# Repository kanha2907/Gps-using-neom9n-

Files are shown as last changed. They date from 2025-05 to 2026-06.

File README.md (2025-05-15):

# Gps-using-neom9n-
      Compact GPS breakout board based on the u-blox NEO-M9N module. Includes support circuitry for battery-backed operation, LEDs, and passives—designed for low-power embedded GPS applications.

# GPS_M Module – Compact GPS Breakout Board

> Compact GPS breakout board based on the **u-blox NEO-M9N** module. Includes support circuitry for battery-backed operation, LEDs, and passives—designed for low-power embedded GPS applications.

---

## 📦 Files Included

- `GPS_m_gerber/`: Full set of Gerber files for PCB manufacturing.
- `neom9n.csv`: Bill of Materials (BOM) with part references, values, and footprints.

## 🧩 Overview

- **GPS Chip:** u-blox NEO-M9N
- **Power Source:** Designed for coin cell MS621T-FL11E
- **Form Factor:** Compact dual-layer board
- **Ideal For:** GPS logging, time synchronization, compact embedded systems

## 🔩 Components Overview

| Reference | Value | Footprint | Quantity |
|---|---|---|---|
| B1 | 6.8MM Coin Cell | MS621T-FL11E | 1 |
| C1 | 47pF Capacitor | GRM1885C1H470JA01D | 1 |
| C3–C6 | 1uF Capacitors | GRM21BR61C105KA01L | 4 |
| CR1 | 1N4148WX-TP Diode | CR_SOD323_MCC | 1 |
| D1, D4 | LEDs | WL-SMCW_0603 | 2 |
| ... | *(See full BOM file)* | | |

> 💡 For the full list of components, refer to `neom9n.csv`.

## 🛠️ How to Use

1. **Order the PCB** using the Gerber files in the `GPS_m_gerber/` folder.
2. **Order parts** based on the BOM file `neom9n.csv`.
3. **Assemble the board** using standard SMD soldering practices.

## 📎 License

This hardware design is released under the [CERN-OHL-W v2](https://ohwr.org/project/cernohl/wikis/home) open hardware license.

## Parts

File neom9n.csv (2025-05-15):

Reference | Value | Datasheet | Footprint | Qty | DNP
B1 | 6.8MM_COIN_CELL |  | MS621T-FL11E:MS621FE-FL11E | 1
C1 | GRM1885C1H470JA01D |  | GRM1885C1H470JA01D:G-188_MUR-L | 1
C3,C4,C5,C6 | GRM21BR61C105KA01L |  | GRM21BR61C105KA01L:CAPC2012X135N | 4
CR1 | 1N4148WX-TP | 1N4148WX-TP | 1N4148WX_TP:CR_SOD323_MCC | 1
D1,D4 | WL-SMCW_0603 |  | 150060BS75000:WL-SMCW_0603 | 2
D3 | PRTR5V0U2F |  | PRTR5V0U2F:FNL6_SOT886_NEX-L | 1
FB1 | BLM21AG102SN1D |  | BLM21AG102SN1D:IND_BLM21_MUR | 1
J1 | SM08B-GHS-TB_LF__SN_ |  | SM08B-GHS-TB_LF__SN_:JST_SM08B-GHS-TB_LF__SN_ | 1
J2,J4,J5,J6 | SM04B-GHS-TB_LF__SN_- |  | SM04B-GHS-TB_LF__SN_-:JST_SM04B-GHS-TB_LF__SN_- | 4
J3 | USB4105-GF-A-060 |  | USB4105-GF-A-060:GCT_USB4105-GF-A-060 | 1
J7 | U.FL-R-SMT-1_10_ |  | U_FL_R_SMT_1_10_:HRS_U.FL-R-SMT-1_10_ | 1
PPS0,PWR\0,SPI0,W1 | 5102TR |  | 5102TR:KEYSTONE_5102TR | 4
R1,R5,R11 | CFR-25JB-52-1K |  | CFR-25JB-52-1K:YAG_CFR25_YAG | 3
R2,R3,R4,R6 | RMCF1206JT33R0 |  | RC0603N_YAG_33:RC0603N_YAG-M | 4
R7 | RC0402FR-072K2L: |  | RC0402FR-072K2L:RC0402N_YAG | 1
R8 | RC0402FR-072K2L |  | RC0402FR-072K2L:RC0402N_YAG-M | 1
R9,R10 | CF12JT27R0 | CF12JT27R0 | CF12JT27R0:RES_CF12_STP | 2
R12,R13 | CRCW06035K10FKEAC |  | CRCW06035K10FKEAC:RESC1608X55N | 2
R14 | SQP10AJB_10R |  | SQP10AJB_10R:YAG_SQP10_YAG | 1
R15 | RC0402FR-07100KL | RC0402FR-07100KL | RC0402N_YAG | 1
R16 | CFR-25JB-52-10K |  | CFR-25JB-52-10K:YAG_CFR25_YAG | 1
U1 | U-BLOX_NEO-M9N |  | RF_GPS:ublox_NEO | 1
U2 | AMS1117-3.3 | http://www.advanced-monolithic.com/pdf/ds1117.pdf | Package_TO_SOT_SMD:SOT-223-3_TabPin2 | 1

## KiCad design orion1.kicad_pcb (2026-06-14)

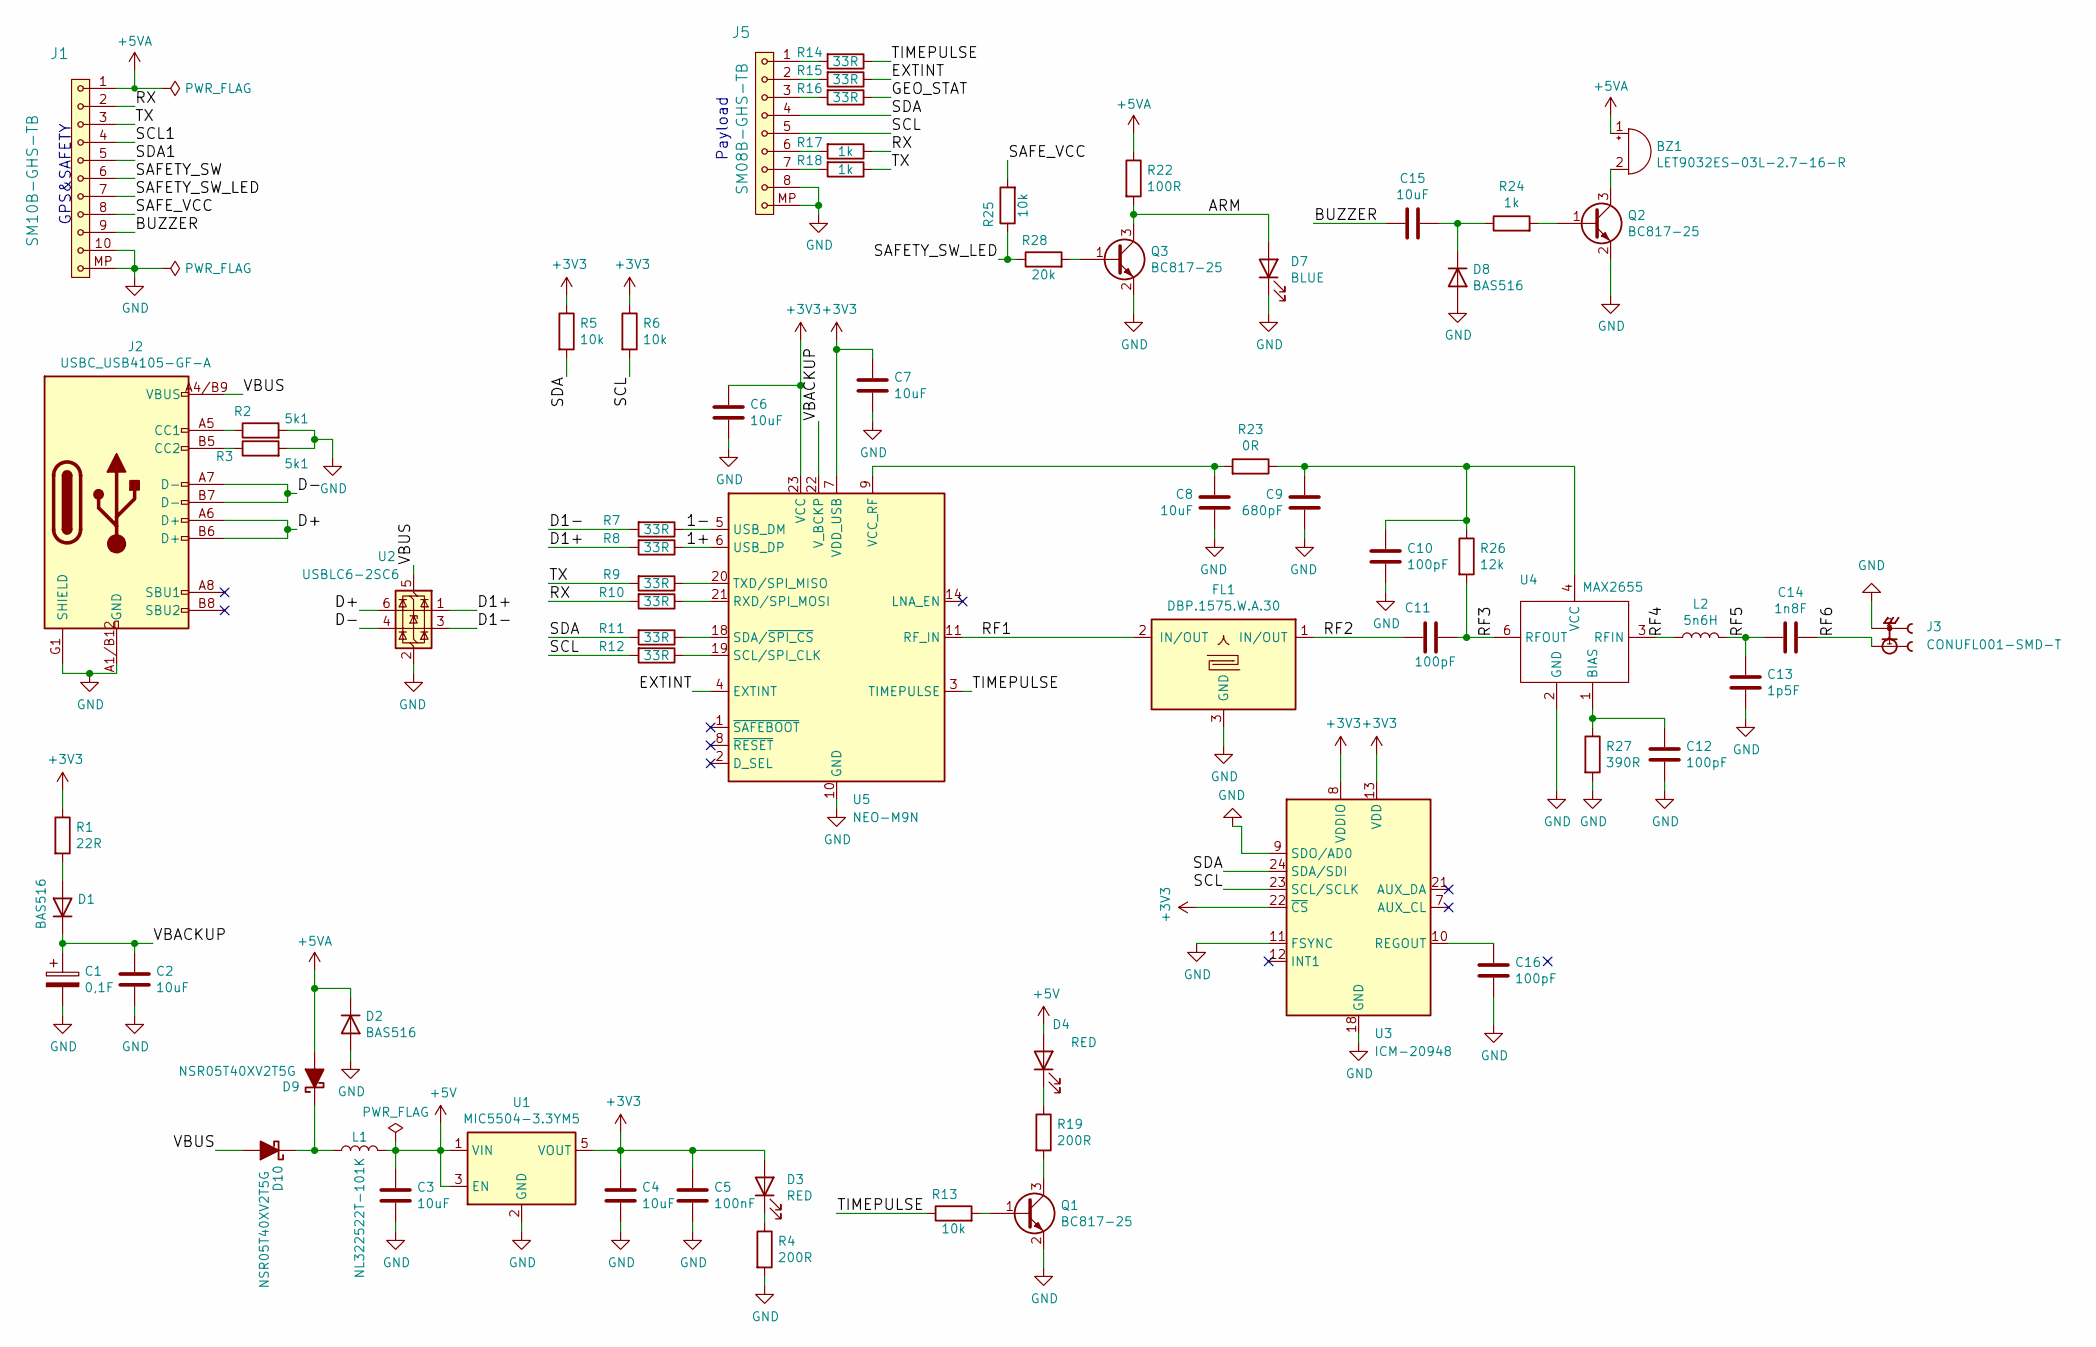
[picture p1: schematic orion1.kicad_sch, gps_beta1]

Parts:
BZ1: LET9032ES-03L-2.7-16-R; MagneticBuzzer_LET9032ES-03L-2.7-16-R
C1: 0,1F; CP_Elec_10x10.5
C2, C3, C4, C6, C7, C8, C15: 10uF; C_0805_2012Metric
C5: 100nF; C_0805_2012Metric
C9: 680pF; C_0805_2012Metric
C10, C11, C12, C16: 100pF; C_0805_2012Metric
C13: 1p5F; C_0805_2012Metric
C14: 1n8F; C_0805_2012Metric
D1, D2, D8: BAS516; D_SOD-523
D3, D4: RED; LED_1206_mill
D7: BLUE; LED_1206_mill
D9, D10: NSR05T40XV2T5G; D_SOD-523
FL1: DBP.1575.W.A.30; SAW DBP.1575.W.A.30
J1: SM10B-GHS-TB; JST_GH_SM10B-GHS-TB_1x10-1MP_P1.25mm_Horizontal
J2: USBC_USB4105-GF-A; USBC GCT_USB4105-GF-A
J3: CONUFL001-SMD-T; LINX_CONUFL001-SMD-T
J5: SM08B-GHS-TB; JST_GH_SM08B-GHS-TB_1x08-1MP_P1.25mm_Horizontal
L1: NL322522T-101K; L_1210_3225Metric
L2: 5n6H; L_0805_2012Metric
Q1, Q2, Q3: BC817-25; SOT-23
R1: 22R; R_0805_2012Metric
R2, R3: 5k1; R_0805_2012Metric
R4, R19: 200R; R_0805_2012Metric
R5, R6, R13, R25: 10k; R_0805_2012Metric
R7, R8, R9, R10, R11, R12, R14, R15, R16: 33R; R_0805_2012Metric
R17, R18, R24: 1k; R_0805_2012Metric
R22: 100R; R_0805_2012Metric
R23: 0R; R_0805_2012Metric
R26: 12k; R_0805_2012Metric
R27: 390R; R_0805_2012Metric
R28: 20k; R_0805_2012Metric
U1: MIC5504-3.3YM5; SOT-23-5
U2: USBLC6-2SC6; SOT-23-6
U3: ICM-20948; InvenSense_QFN-24_3x3mm_P0.4mm
U4: MAX2655; SOT-363_SC-70-6
U5: NEO-M9N; ublox_NEO

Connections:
+3V3: C4.1, C5.1, C6.1, C7.1, D3.2 (A), R1.1, R5.1, R6.1, U1.5 (VOUT), U3.8 (VDDIO), U3.13 (VDD), U3.22 (~CS), U5.7 (VDD_USB), U5.23 (VCC)
+5V: C3.1, D4.2 (A), L1.2, U1.1 (VIN), U1.3 (EN)
+5VA: BZ1.1 (+), D2.1 (K), D9.2 (A), J1.1, R22.1
/1+: R8.1, U5.6 (USB_DP)
/1-: R7.1, U5.5 (USB_DM)
/ARM: D7.2 (A), Q3.3 (C), R22.2
/BUZZER: C15.1, J1.9
/D1+: R8.2, U2.1 (I/O1)
/D1-: R7.2, U2.3 (I/O2)
/D+: J2.A6 (D+), J2.B6 (D+), U2.6 (I/O1)
/D-: J2.A7 (D-), J2.B7 (D-), U2.4 (I/O2)
/EXTINT: R15.1, U5.4 (EXTINT)
/GEO_STAT: R16.1; also elsewhere on the board
/RF1: FL1.2 (IN/OUT), U5.11 (RF_IN)
/RF2: C11.1, FL1.1 (IN/OUT)
/RF3: C11.2, R26.2, U4.6 (RFOUT)
/RF4: L2.1, U4.3 (RFIN)
/RF5: C13.2, C14.1, L2.2
/RF6: C14.2, J3.1
/RX: J1.2, R10.2, R17.1
/SAFETY_SW: J1.6
/SAFETY_SW_LED: J1.7, R25.1, R28.1
/SAFE_VCC: J1.8, R25.2
/SCL: J5.5, R6.2, R12.2, U3.23 (SCL/SCLK)
/SCL1: J1.4
/SDA: J5.4, R5.2, R11.2, U3.24 (SDA/SDI)
/SDA1: J1.5
/TIMEPULSE: R13.1, R14.1, U5.3 (TIMEPULSE)
/TX: J1.3, R9.2, R18.1
/VBACKUP: C1.1, C2.1, D1.1 (K), U5.22 (V_BCKP)
/VBUS: D10.2 (A), J2.A4/B9 (VBUS), J2.B4/A9 (VBUS), U2.5 (VBUS)
GND: C1.2, C2.2, C3.2, C4.2, C5.2, C6.2, C7.2, C8.2, C9.2, C10.2, C12.2, C13.1, C16.2, D2.2 (A), D7.1 (K), D8.2 (A), FL1.3 (GND), J1.10, J1.MP, J2.A1/B12 (GND), J2.B1/A12 (GND), J2.G1 (SHIELD), J2.G2 (SHIELD), J2.G3 (SHIELD), J2.G4 (SHIELD), J3.2, J3.3, J5.8, J5.MP, Q1.2 (E), Q2.2 (E), Q3.2 (E), R2.2, R3.2, R4.2, R27.2, U1.2 (GND), U2.2 (GND), U3.9 (SDO/AD0), U3.11 (FSYNC), U3.18 (GND), U3.20 (GND), U4.2 (GND), U4.5 (GND), U5.10 (GND), U5.12 (GND), U5.13 (GND), U5.24 (GND); also elsewhere on the board
unnamed: BZ1.2 (-), Q2.3 (C)
unnamed: D1.2 (A), R1.2
unnamed: D3.1 (K), R4.1
unnamed: D4.1 (K), R19.1
unnamed: C15.2, D8.1 (K), R24.1
unnamed: D9.1 (K), D10.1 (K), L1.1
unnamed: J2.A5 (CC1), R2.1
unnamed: J2.B5 (CC2), R3.1
unnamed: J5.1, R14.2
unnamed: J5.2, R15.2
unnamed: J5.3, R16.2
unnamed: J5.6, R17.2
unnamed: J5.7, R18.2
unnamed: Q1.1 (B), R13.2
unnamed: Q1.3 (C), R19.2
unnamed: Q2.1 (B), R24.2
unnamed: Q3.1 (B), R28.2
unnamed: C16.1, U3.10 (REGOUT)
unnamed: C12.1, R27.1, U4.1 (BIAS)
unnamed: C9.1, C10.1, R23.1, R26.1, U4.4 (VCC)
unnamed: R10.1, U5.21 (RXD/SPI_MOSI)
unnamed: R12.1, U5.19 (SCL/SPI_CLK)
unnamed: R11.1, U5.18 (SDA/~SPI_CS)
unnamed: R9.1, U5.20 (TXD/SPI_MISO)
unnamed: C8.1, R23.2, U5.9 (VCC_RF)

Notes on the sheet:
GPS&SAFETY
Payload

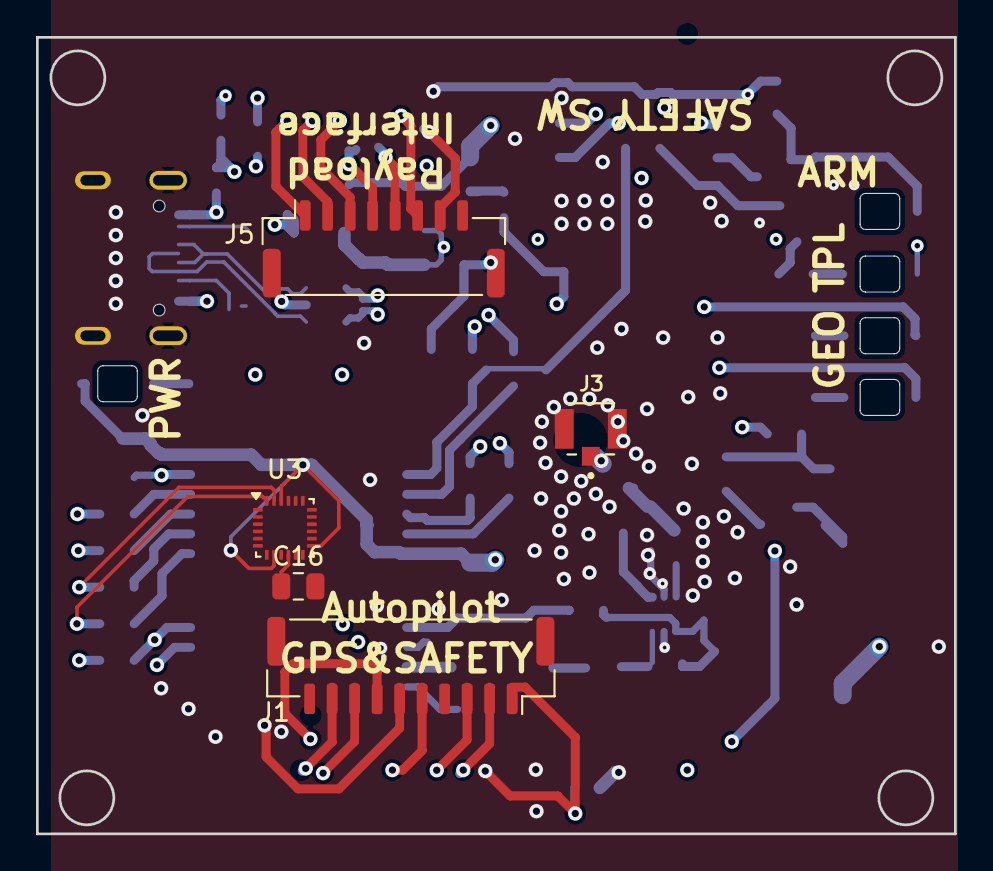
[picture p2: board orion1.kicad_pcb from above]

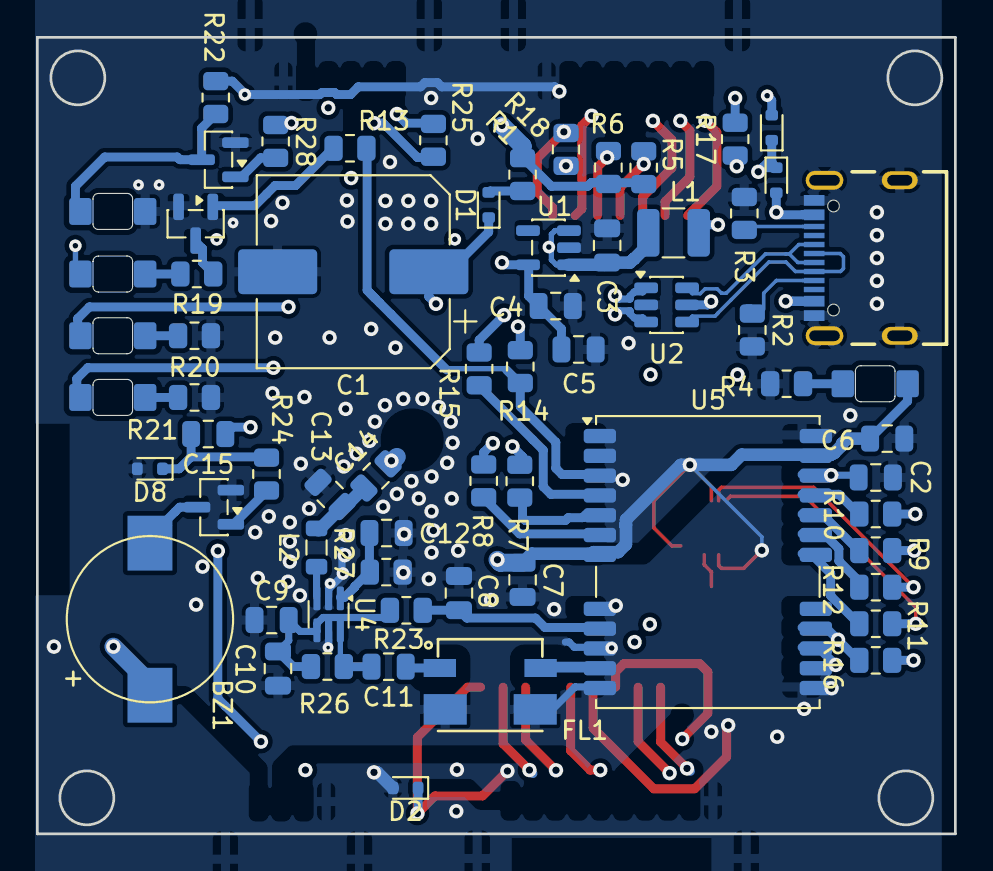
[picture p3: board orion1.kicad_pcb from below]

Board: 4 copper layers, 51.0 x 44.2 mm, 70 parts (65 on the bottom side), 56 nets.

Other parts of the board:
D5: YELLOW; LED_1206_mill
D6: GREEN; LED_1206_mill
R20, R21: 100R; R_0805_2012Metric

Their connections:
/GEO_STAT: D5.2 (A); also elsewhere on the board
GND: R20.2, R21.2; also elsewhere on the board
unnamed: D5.1 (K), R20.1
unnamed: D6.1 (K), R21.1
